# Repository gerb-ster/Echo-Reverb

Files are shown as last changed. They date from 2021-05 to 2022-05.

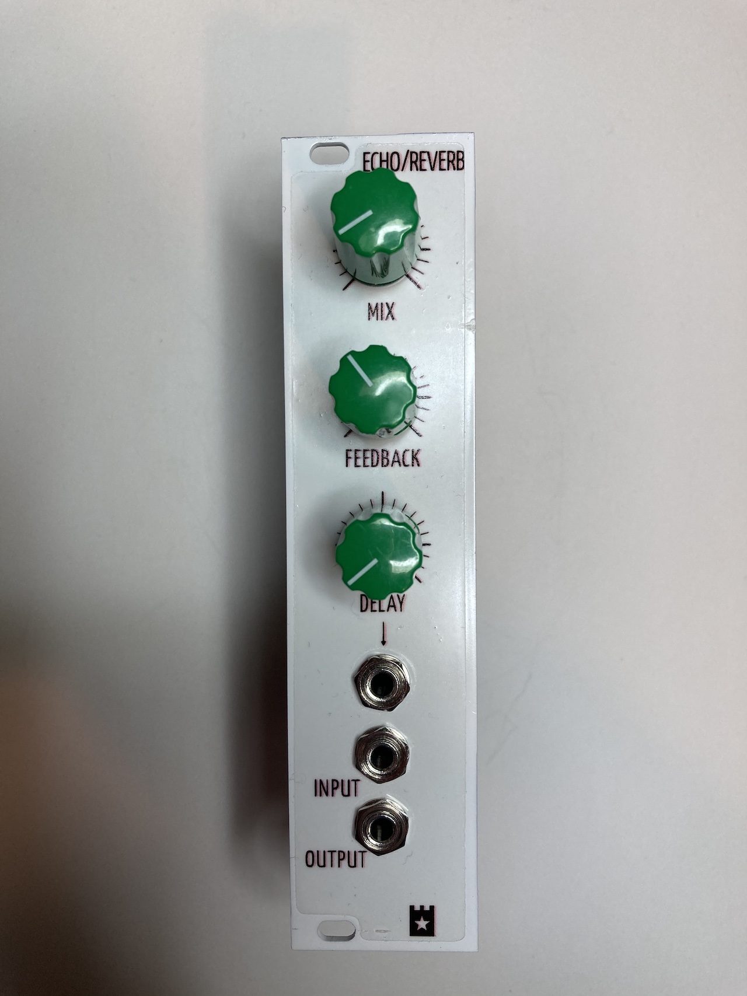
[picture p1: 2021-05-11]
images/IMG_3549.jpeg

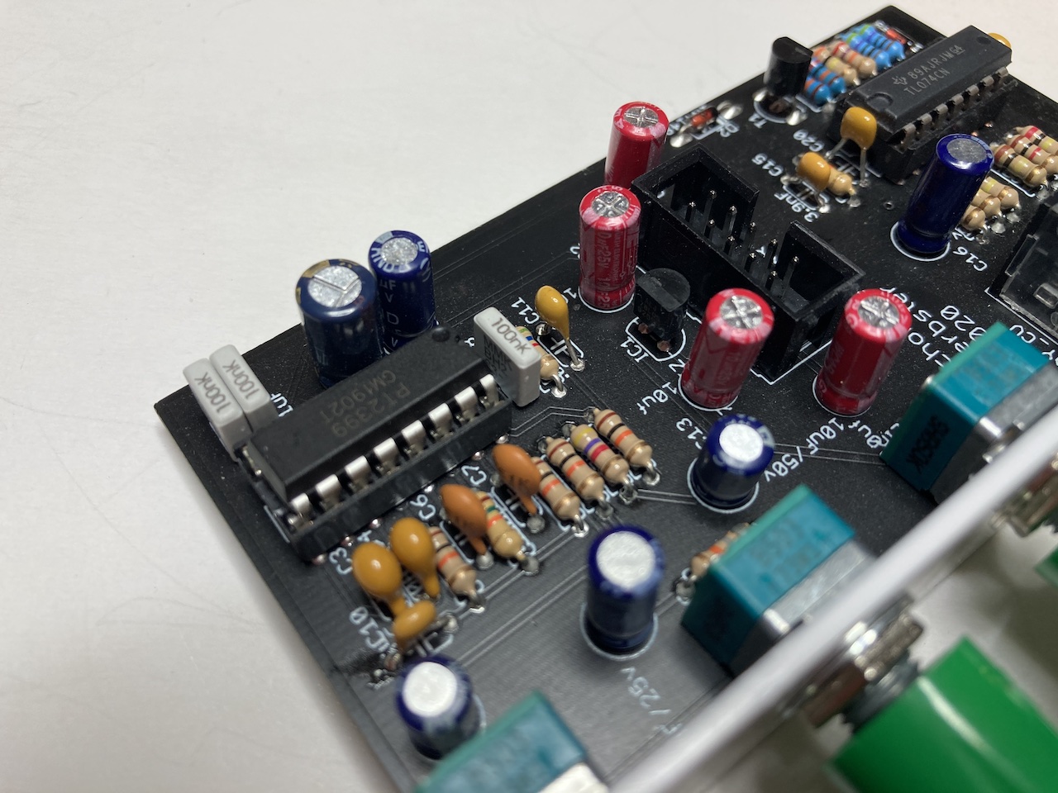
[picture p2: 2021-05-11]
images/IMG_3554.jpeg

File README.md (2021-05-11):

# Echo/Reverb

Next, another effect module. I bought a bunch of PT2399 IC’s from China so I made his Echo/Reverb unit. It’s basically a clone of the Echo unit from Synthrotek.

## Status: Finished

- done: first schematic & board design
- done: breadboard and test
- done: design frontpanel
- done: order PCB and build prototype

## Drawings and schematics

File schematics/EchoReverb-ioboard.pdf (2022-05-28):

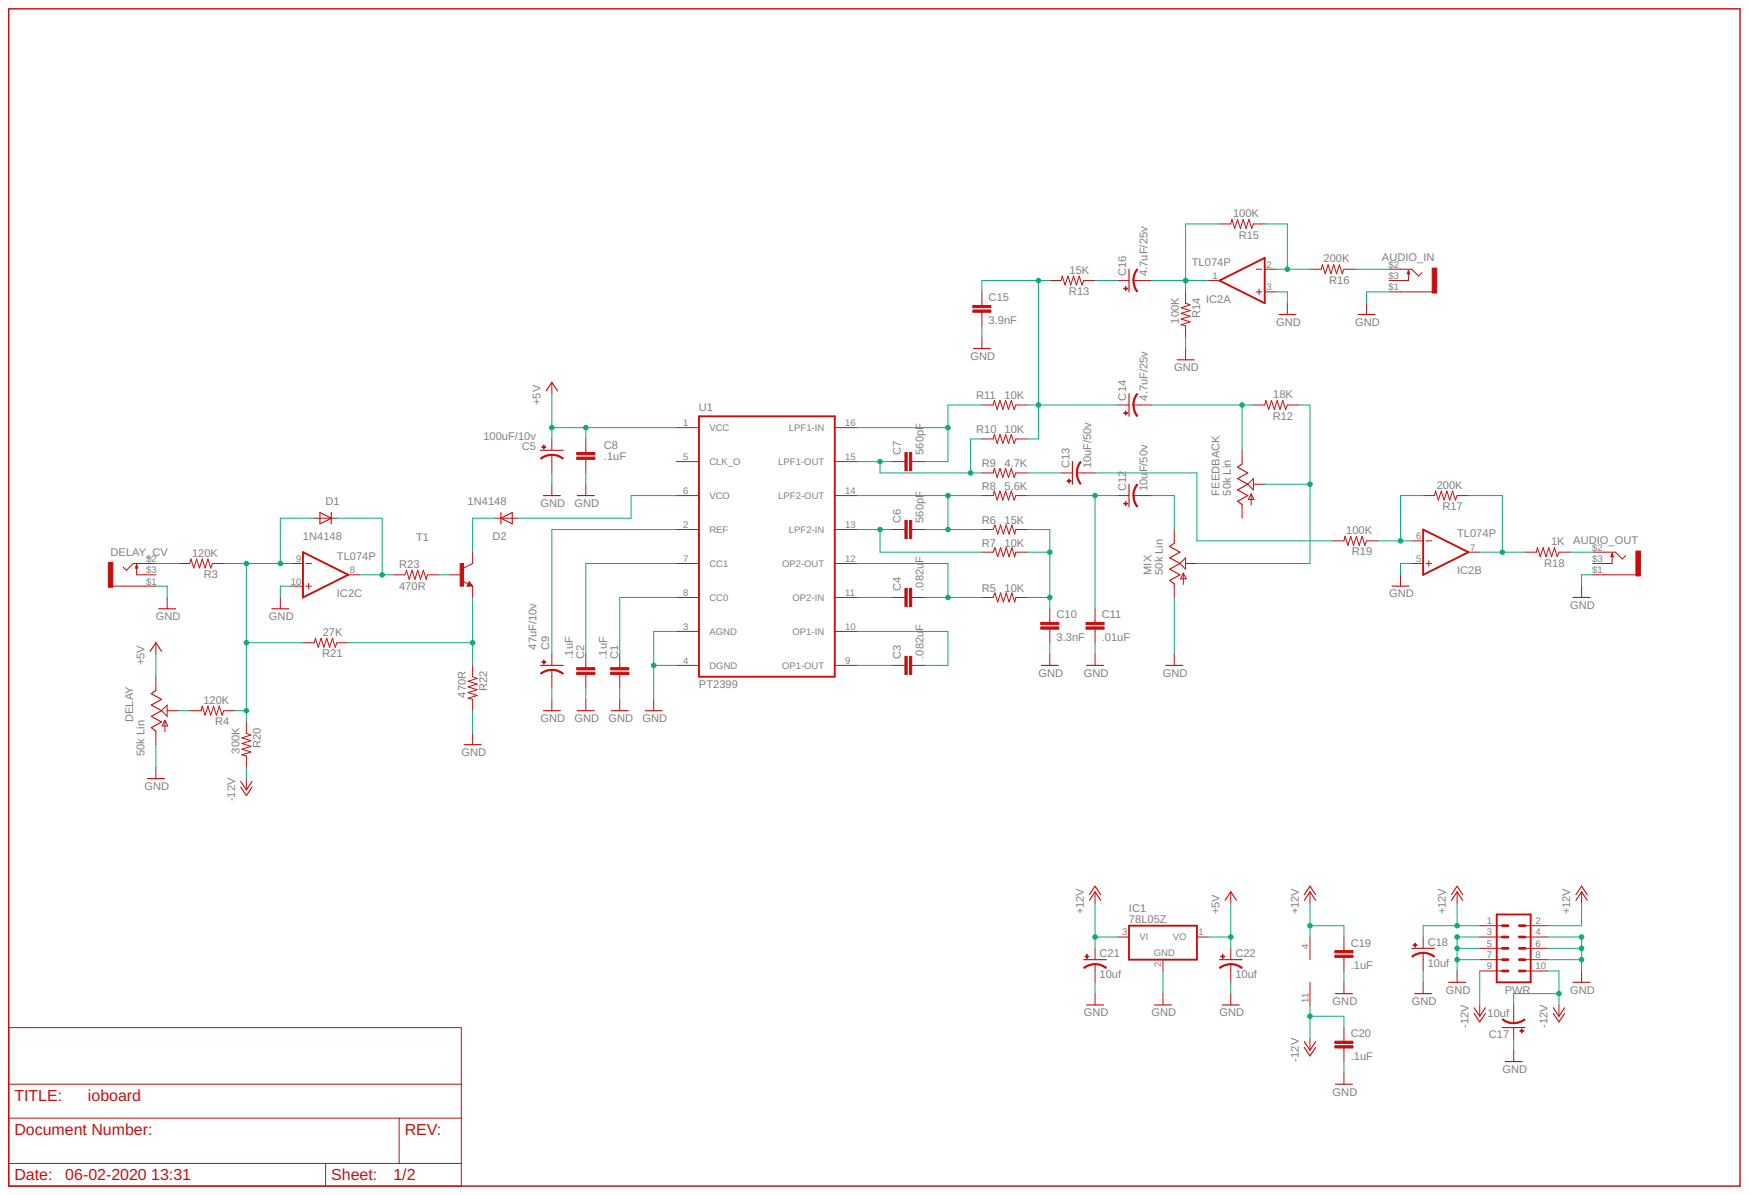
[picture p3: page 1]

Document Number: | REV:

Date: 06-02-2020 13:31 | Sheet: 1/2

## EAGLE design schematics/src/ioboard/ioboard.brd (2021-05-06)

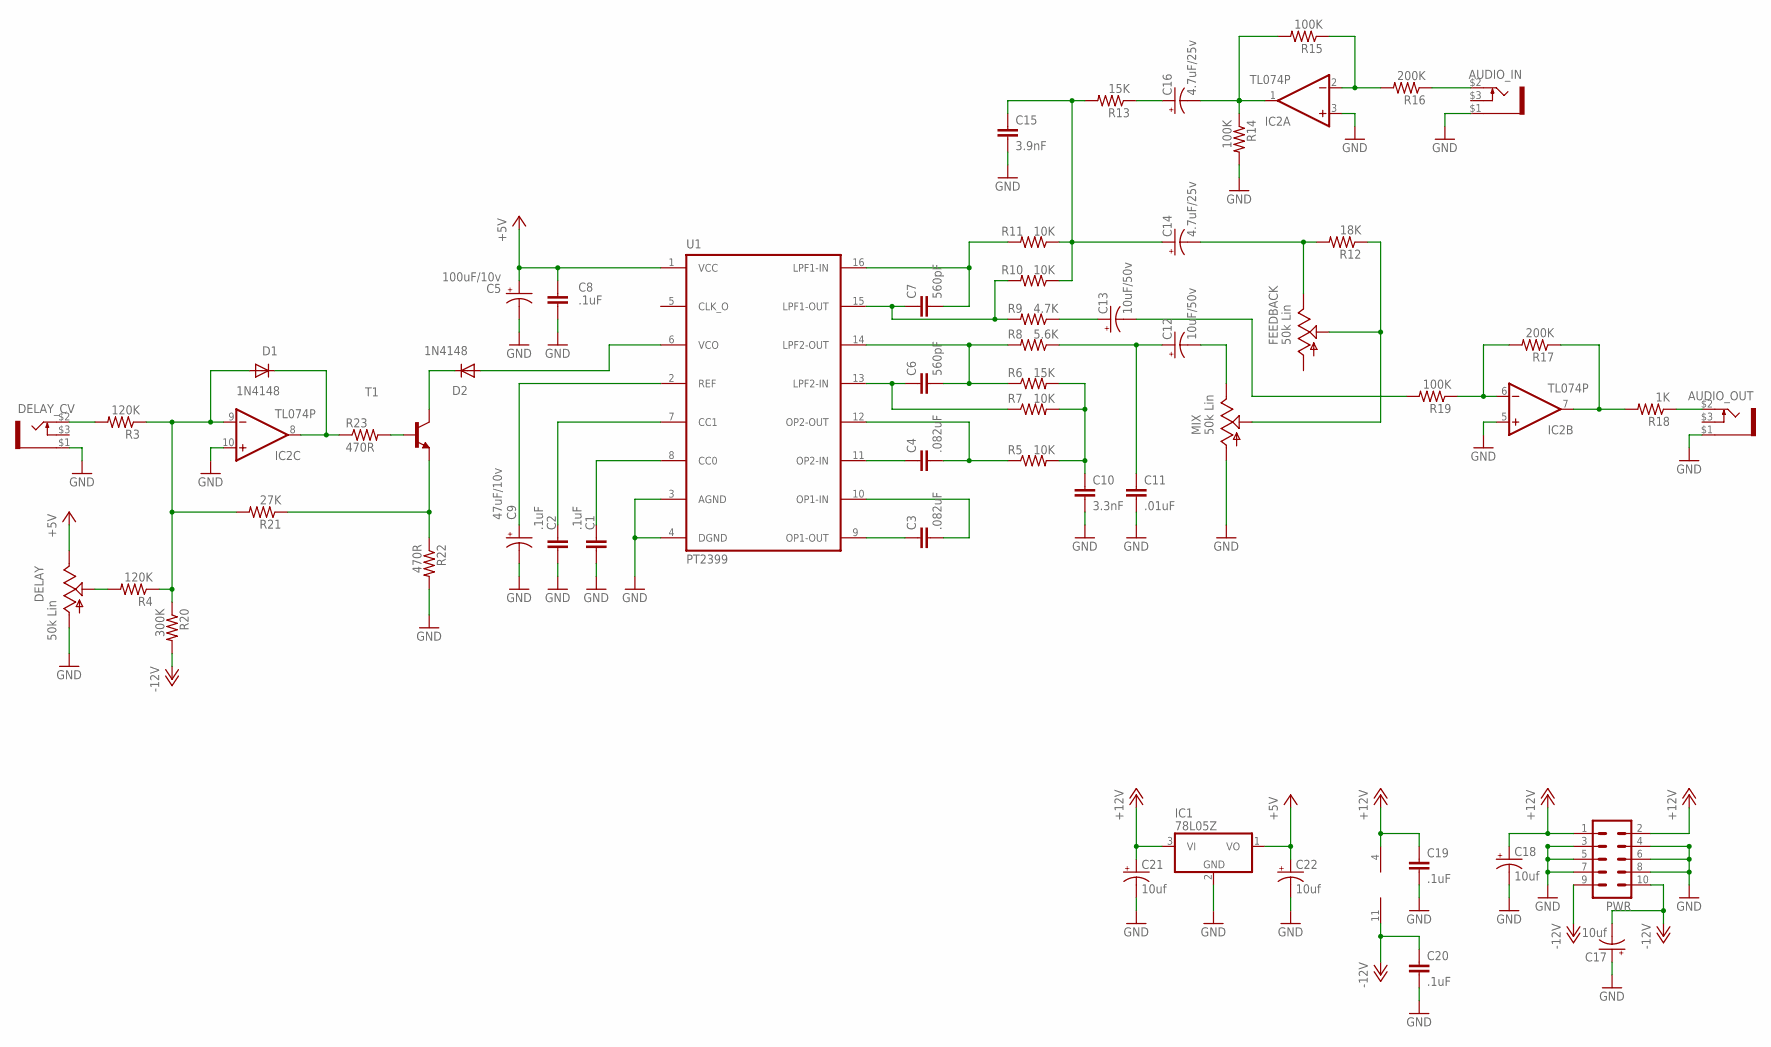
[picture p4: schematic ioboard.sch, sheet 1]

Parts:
AUDIO_IN: PJ-323PJ-323; PJ-323
AUDIO_OUT: PJ-323PJ-323; PJ-323
C1, C2, C8, C19, C20: .1uF; C050-024X044
C3, C4: .082uF; C050-024X044
C5: 100uF/10v; E2,5-6
C6, C7: 560pF; C050-024X044
C9: 47uF/10v; E2,5-6
C10: 3.3nF; C050-024X044
C11: .01uF; C050-024X044
C12, C13: 10uF/50v; E2,5-6
C14, C16: 4.7uF/25v; E2,5-6
C15: 3.9nF; C050-024X044
C17, C18, C21, C22: 10uf; E2,5-5
D1, D2: 1N4148; DO35-7
DELAY: 50k Lin; EVUF
DELAY_CV: PJ-323PJ-323; PJ-323
FEEDBACK: 50k Lin; EVUF
IC1: 78L05Z; TO92
IC2: TL074P; DIL14
MIX: 50k Lin; EVUF
PWR: ML10
R3, R4: 120K; 0207/7
R5, R7, R10, R11: 10K; 0207/7
R6, R13: 15K; 0207/7
R8: 5.6K; 0207/7
R9: 4.7K; 0207/7
R12: 18K; 0207/7
R14, R15, R19: 100K; 0207/7
R16, R17: 200K; 0207/7
R18: 1K; 0207/7
R20: 300K; 0207/7
R21: 27K; 0207/7
R22, R23: 470R; 0207/7
T1: 2N3904-NPN-TO92-EBC; TO92-EBC
U1: PT2399; DIL16

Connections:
+5V: C5.+, C8.1, C22.+, DELAY.3 (E), IC1.1 (VO), U1.1 (VCC)
+12V: C18.+, C19.1, C21.+, IC1.3 (VI), IC2.4 (V+), PWR.1, PWR.2
-12V: C17.-, C20.1, IC2.11 (V-), PWR.9, PWR.10, R20.2
DELAY: D2.A, U1.6 (VCO)
GND: AUDIO_IN.$1 (3), AUDIO_OUT.$1 (3), C1.2, C2.2, C5.-, C8.2, C9.-, C10.2, C11.2, C15.2, C17.+, C18.-, C19.2, C20.2, C21.-, C22.-, DELAY.1 (A), DELAY_CV.$1 (3), IC1.2 (GND), IC2.3 (+IN), IC2.5 (+IN), IC2.10 (+IN), MIX.1 (A), PWR.3, PWR.4, PWR.5, PWR.6, PWR.7, PWR.8, R14.2, R22.2, U1.3 (AGND), U1.4 (DGND)
unnamed: C1.1, U1.8 (CC0)
unnamed: C2.1, U1.7 (CC1)
unnamed: C3.2, U1.10 (OP1-IN)
unnamed: C3.1, U1.9 (OP1-OUT)
unnamed: C4.1, U1.11 (OP2-IN)
unnamed: C4.2, R5.1, U1.12 (OP2-OUT)
unnamed: C6.1, R7.1, U1.13 (LPF2-IN)
unnamed: C7.1, R9.2, R10.2, U1.15 (LPF1-OUT)
unnamed: C6.2, R6.1, R8.2, U1.14 (LPF2-OUT)
unnamed: C7.2, R11.2, U1.16 (LPF1-IN)
unnamed: C9.+, U1.2 (REF)
unnamed: C10.1, R5.2, R6.2, R7.2
unnamed: C11.1, C12.+, R8.1
unnamed: C12.-, MIX.3 (E)
unnamed: C13.+, R9.1
unnamed: C14.+, C15.1, R10.1, R11.1, R13.2
unnamed: C14.-, FEEDBACK.3 (E), R12.2
unnamed: FEEDBACK.2 (S), MIX.2 (S), R12.1
unnamed: C16.+, R13.1
unnamed: C16.-, IC2.1 (OUT), R14.1, R15.2
unnamed: IC2.6 (-IN), R17.2, R19.1
unnamed: AUDIO_IN.$2 (1), R16.1
unnamed: IC2.2 (-IN), R15.1, R16.2
unnamed: IC2.7 (OUT), R17.1, R18.2
unnamed: AUDIO_OUT.$2 (1), R18.1
unnamed: DELAY.2 (S), R4.2
unnamed: DELAY_CV.$2 (1), R3.2
unnamed: D1.A, IC2.9 (-IN), R3.1, R4.1, R20.1, R21.2
unnamed: D1.C, IC2.8 (OUT), R23.1
unnamed: R21.1, R22.1, T1.E
unnamed: R23.2, T1.B
unnamed: D2.C, T1.C
OUT: C13.-, R19.2

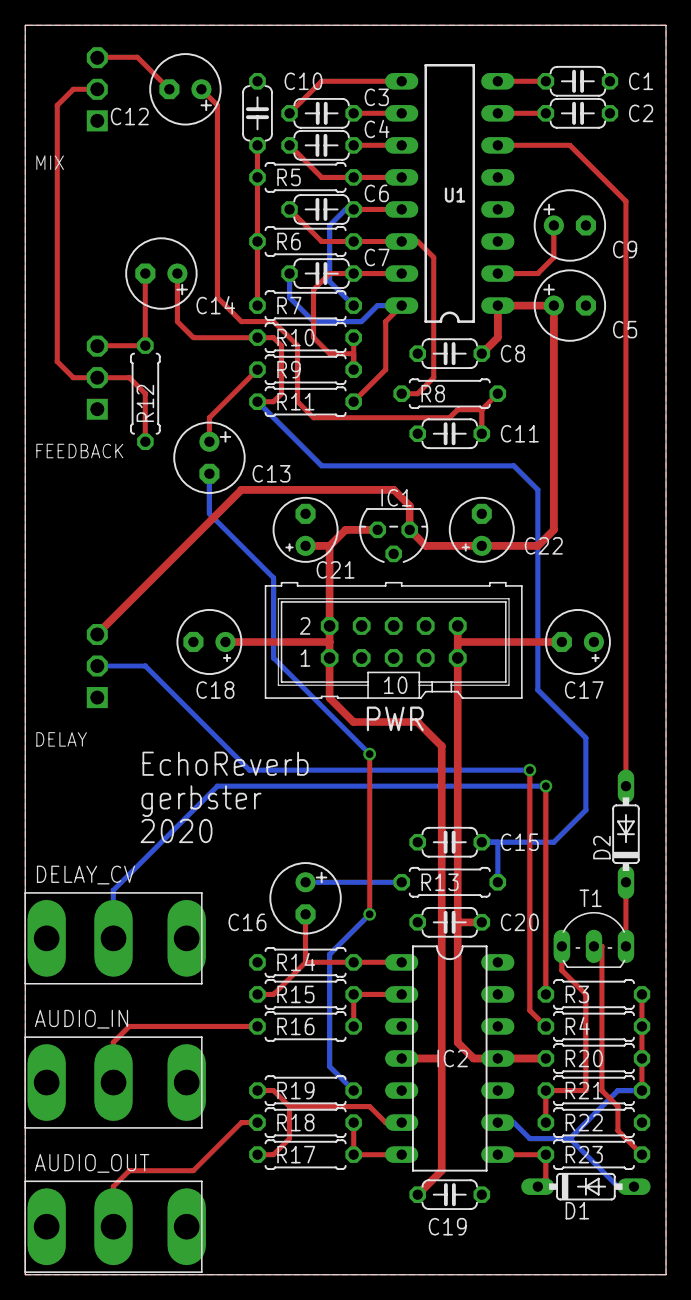
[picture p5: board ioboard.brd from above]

Board: 2 copper layers, 50.8 x 99.1 mm, 56 parts (0 on the bottom side), 38 nets.

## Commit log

2021-05-06 some files
    [EchoReverbUnit.brd, EchoReverbUnit.sch]
2021-05-07 Added files & structure
    [EchoReverb-ioboard.GBL, EchoReverb-ioboard.GBO, EchoReverb-ioboard.GBP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]
2021-08-06 Updated some schematics and docs
    [EchoReverb-ioboard.GBL, EchoReverb-ioboard.GBO, EchoReverb-ioboard.GBP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]
2021-08-10 Fixed some bugs and updated documentation
    [EchoReverb-ioboard.XLN, gerber_job.gbrjob]
2022-04-20 Some updates & bugfixes
    [EchoReverb-ioboard.XLN, gerber_job.gbrjob]
2022-04-22 Fixed schematics & descriptions
    [EchoReverb-ioboard.XLN, gerber_job.gbrjob]
2022-05-17 Updated Firmware
    [EchoReverb-ioboard.XLN, gerber_job.gbrjob]
2022-05-18 Updated Faceplates
    [EchoReverb-ioboard.XLN, gerber_job.gbrjob]
2022-05-18 Fixed issues
    [EchoReverb-ioboard.XLN, gerber_job.gbrjob]
2022-05-21 Fixed schematics
    [EchoReverb-ioboard.XLN, gerber_job.gbrjob]
2022-05-28 General updates
    [copper_bottom.gbr, copper_top.gbr, drills.xln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]
